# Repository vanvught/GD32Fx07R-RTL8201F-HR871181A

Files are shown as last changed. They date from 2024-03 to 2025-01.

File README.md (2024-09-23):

# GD32Fx07R development board with RTL8201F and HR871181A

This board can be used with the `GD32F107Rx` , `GD32F207Rx`, `GD32F407Rx` MCU's. 

More information [https://www.gd32-dmx.org/dev-board.html](https://www.gd32-dmx.org/dev-board.html)



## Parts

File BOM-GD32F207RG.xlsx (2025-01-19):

Qty | Designator | Footprint | Comment | LCSC Part #
19 | C1, C3, C8, C9, C10, C11, C12, C13, C16, C17, C18, C19, C20, C22, C23, C24, C25, C26, C27 | C0603 | 100n | C14663
2 | C2, C4 | C0603 | 20pF | C38523
1 | C28 | C1206 | 1nF/2kV | C9196
2 | C5, C6 | C0603 | 12pF | C38523
4 | C7, C14, C15, C21 | A/3216-18R | 10uF | C7171
2 | D1, D2 | SOD323-R | 1N5819 | C191023
2 | FL1, FL2 | 603 | MZAS1608G121-1R3TF0603 | C709642
1 | IC1 | QFN50P500X500X100-33N | RTL8201F-VB-CG | C45044
1 | J4 | 10118192-0002LF | 10118192-0002LF | C2972784
1 | J6 | HR871181A | HR871181A | C49312
4 | LED1, LED2, LED3, LED4 | CHIP-LED0603 | LED | C2286
1 | Q1 | CSM-7X-DU | 25 MHz | C14872
1 | Q2 | 3.2X1.5 | 32.768kHz | C32346
3 | R1, R2, R9 | R0603 | 10K | C25804
2 | R14, R15 | R0603 | 510 | C23193
1 | R21 | R0603 | 2K49 | C100897
1 | R3 | R0603 | 1M | C22935
2 | R4, R12 | R0603 | 1K5 | C22843
4 | R5, R7, R17, R18 | R0603 | 22R | C23345
8 | R6, R8, R10, R11, R13, R16, R19, R20 | R0603 | 4K7 | C23162
1 | RN1 | 4X0402ARV341 | 2K | C44891
2 | RN2, RN3 | 4X0402ARV341 | 33 | C25501
1 | SW1 | EVQ-Q2 | BOOT0 | C221880
1 | SW2 | EVQ-Q2 | KEY1 | C221880
1 | SW3 | EVQ-Q2 | KEY2 | C221880
1 | SW4 | EVQ-Q2 | RESET | C221880
1 | U1 | SO08-EIAJ | W25Q128JVSIQ | C97521
1 | U2 | LQFP64 | GD32F207RGT6 | C2976322
1 | U3 | SOT23-5 | AP2112-3.3 | C51118
72

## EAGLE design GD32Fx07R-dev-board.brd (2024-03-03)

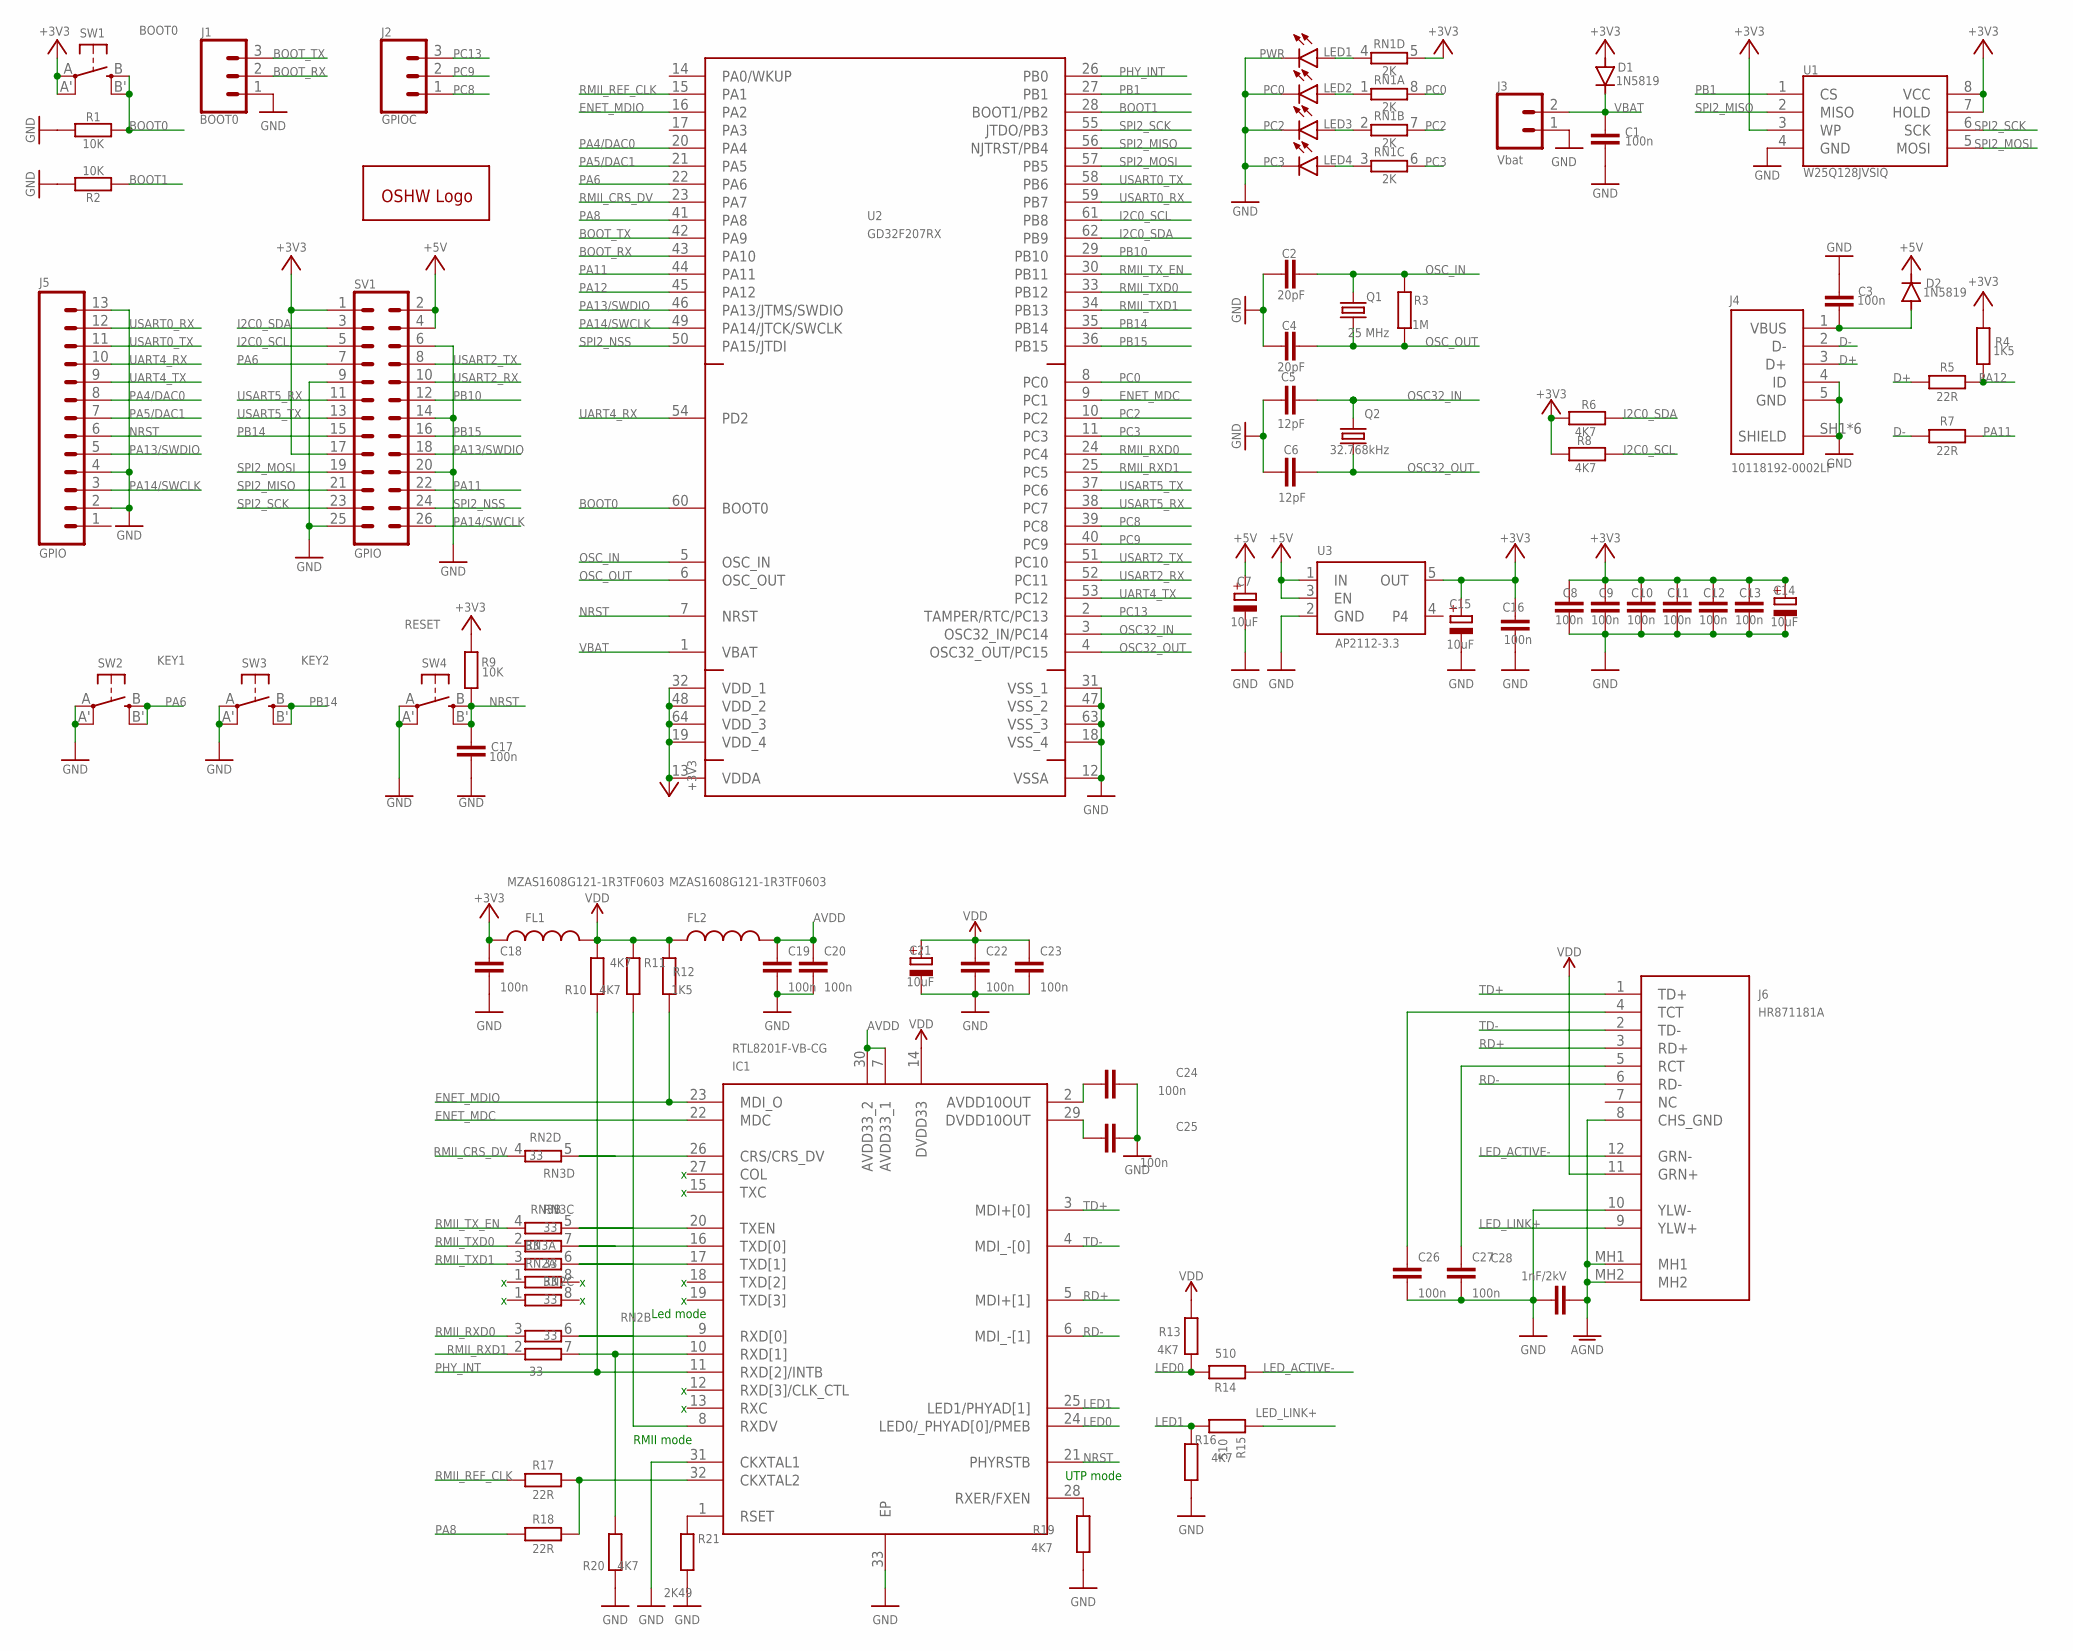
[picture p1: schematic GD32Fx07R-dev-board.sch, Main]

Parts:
C1, C3, C8, C9, C10, C11, C12, C13, C16, C17, C18, C19, C20, C22, C23, C24, C25, C26, C27: 100n; C0603; JLCPCB C14663
C2, C4: 20pF; C0603; JLCPCB C38523
C5, C6: 12pF; C0603; JLCPCB C38523
C7, C14, C15, C21: 10uF; A/3216-18R; JLCPCB C7171
C28: 1nF/2kV; C1206; JLCPCB C9196
D1, D2: 1N5819; SOD323-R; JLCPCB C191023
FL1, FL2: MZAS1608G121-1R3TF0603; 0603
GOLD_ORB_SM1: OSHWLOGOLOGO5MM; OSHW_5MM
IC1: RTL8201F-VB-CG; QFN50P500X500X100-33N
J1: BOOT0; 1X03
J2: GPIOC; 1X03
J3: Vbat; 1X02_NO_SILK
J4: 10118192-0002LF; JLCPCB C2972784
J5: GPIO; 1X13
J6: HR871181A
LED1: PWR; CHIP-LED0603; JLCPCB C72043
LED2: PC0; CHIP-LED0603; JLCPCB C72043
LED3: PC2; CHIP-LED0603; JLCPCB C72043
LED4: PC3; CHIP-LED0603; JLCPCB C72043
Q1: 25 MHz; CSM-7X-DU; JLCPCB C14872
Q2: 32.768kHz; 3.2X1.5; JLCPCB C32346
R1, R2, R9: 10K; R0603; JLCPCB C25804
R3: 1M; R0603; JLCPCB C22935
R4, R12: 1K5; R0603; JLCPCB C22843
R5, R7, R17, R18: 22R; R0603; JLCPCB C23345
R6, R8, R10, R11, R13, R16, R19, R20: 4K7; R0603; JLCPCB C23162
R14, R15: 510; R0603; JLCPCB C23193
R21: 2K49; R0603; JLCPCB C100897
RN1: 2K; 4X0402ARV341; JLCPCB C44891
RN2, RN3: 33; 4X0402ARV341; JLCPCB C25501
SV1: GPIO; MA13-2
SW1: BOOT0; EVQ-Q2; JLCPCB C221880
SW2: KEY1; EVQ-Q2; JLCPCB C221880
SW3: KEY2; EVQ-Q2; JLCPCB C221880
SW4: RESET; EVQ-Q2; JLCPCB C221880
U1: W25Q128JVSIQ; SO08-EIAJ; JLCPCB C97521
U2: GD32F207RX; LQFP64
U3: AP2112-3.3; SOT23-5; JLCPCB C51118

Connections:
+3V3: C8.1, C9.1, C10.1, C11.1, C12.1, C13.1, C14.+, C15.+, C16.1, C18.1, D1.A, FL1.1, R4.2, R6.2, R8.2, R9.2, RN1.5 (2), SV1.1, SV1.17, SW1.A, SW1.A' (P1), U1.3 (WP), U1.7 (HOLD), U1.8 (VCC), U2.13 (VDDA), U2.19 (VDD_4), U2.32 (VDD_1), U2.48 (VDD_2), U2.64 (VDD_3), U3.5 (OUT)
+5V: C7.+, D2.C, SV1.2, SV1.4, U3.1 (IN), U3.3 (EN)
AGND: C28.2, J6.8 (CHS_GND), J6.MH1, J6.MH2
AVDD: C19.1, C20.1, FL2.2, IC1.7 (AVDD33_1), IC1.30 (AVDD33_2)
BOOT0: R1.2, SW1.B (S), SW1.B' (S1), U2.60 (BOOT0)
BOOT1: R2.1, U2.28 (BOOT1/PB2)
BOOT_RX: J1.2, U2.43 (PA10)
BOOT_TX: J1.3, U2.42 (PA9)
CLOCK: IC1.32 (CKXTAL2), R17.2, R18.2
D+: J4.3 (D+), R5.1
D-: J4.2 (D-), R7.1
ENET_MDC: IC1.22 (MDC), U2.9 (PC1)
ENET_MDIO: IC1.23 (MDI_O), R12.1, U2.16 (PA2)
GND: C1.2, C2.1, C3.1, C4.1, C5.1, C6.1, C7.-, C8.2, C9.2, C10.2, C11.2, C12.2, C13.2, C14.-, C15.-, C16.2, C17.2, C18.2, C19.2, C20.2, C21.-, C22.2, C23.2, C24.1, C25.1, C26.2, C27.2, C28.1, IC1.31 (CKXTAL1), IC1.33 (EP), J1.1, J3.1, J4.4 (ID), J4.5 (GND), J4.SH1 (SHIELD), J4.SH2 (SHIELD), J4.SH3 (SHIELD), J4.SH4 (SHIELD), J4.SH5 (SHIELD), J4.SH6 (SHIELD), J5.2, J5.4, J5.13, J6.10 (YLW-), LED1.C, LED2.C, LED3.C, LED4.C, R1.1, R2.2, R16.1, R19.1, R20.1, R21.2, SV1.6, SV1.9, SV1.14, SV1.20, SV1.25, SW2.A, SW2.A' (P1), SW3.A, SW3.A' (P1), SW4.A, SW4.A' (P1), U1.4 (GND), U2.12 (VSSA), U2.18 (VSS_4), U2.31 (VSS_1), U2.47 (VSS_2), U2.63 (VSS_3), U3.2 (GND)
I2C0_SCL: R8.1, SV1.5, U2.61 (PB8)
I2C0_SDA: R6.1, SV1.3, U2.62 (PB9)
LED0: IC1.24 (LED0/_PHYAD[0]/PMEB), R13.1, R14.2
LED1: IC1.25 (LED1/PHYAD[1]), R15.2, R16.2
LED_ACTIVE-: J6.12 (GRN-), R14.1
LED_LINK+: J6.9 (YLW+), R15.1
unnamed: C24.2, IC1.2 (AVDD10OUT)
unnamed: IC1.1 (RSET), R21.1
unnamed: IC1.8 (RXDV), R11.2
unnamed: C25.2, IC1.29 (DVDD10OUT)
unnamed: IC1.28 (RXER/FXEN), R19.2
unnamed: C27.1, J6.5 (RCT)
unnamed: LED2.A, RN1.1
unnamed: LED3.A, RN1.2 (1)
unnamed: C26.1, J6.4 (TCT)
unnamed: LED4.A, RN1.3 (1)
unnamed: LED1.A, RN1.4 (1)
NRST: C17.1, IC1.21 (PHYRSTB), J5.6, R9.1, SW4.B (S), SW4.B' (S1), U2.7 (NRST)
OSC32_IN: C5.2, Q2.2, U2.3 (OSC32_IN/PC14)
OSC32_OUT: C6.2, Q2.1, U2.4 (OSC32_OUT/PC15)
OSC_IN: C2.2, Q1.2, R3.1, U2.5 (OSC_IN)
OSC_OUT: C4.2, Q1.1, R3.2, U2.6 (OSC_OUT)
PA4/DAC0: J5.8, U2.20 (PA4)
PA5/DAC1: J5.7, U2.21 (PA5)
PA6: SV1.7, SW2.B (S), SW2.B' (S1), U2.22 (PA6)
PA8: R18.1, U2.41 (PA8)
PA11: R7.2, SV1.22, U2.44 (PA11)
PA12: R4.1, R5.2, U2.45 (PA12)
PA13/SWDIO: J5.5, SV1.18, U2.46 (PA13/JTMS/SWDIO)
PA14/SWCLK: J5.3, SV1.26, U2.49 (PA14/JTCK/SWCLK)
PB1: U1.1 (CS), U2.27 (PB1)
PB10: SV1.12, U2.29 (PB10)
PB14: SV1.15, SW3.B (S), SW3.B' (S1), U2.35 (PB14)
PB15: SV1.16, U2.36 (PB15)
PC0: RN1.8 (2), U2.8 (PC0)
PC2: RN1.7 (2), U2.10 (PC2)
PC3: RN1.6 (2), U2.11 (PC3)
PC8: J2.1, U2.39 (PC8)
PC9: J2.2, U2.40 (PC9)
PC13: J2.3, U2.2 (TAMPER/RTC/PC13)
PHY_INT: IC1.11 (RXD[2]/INTB), R10.1, U2.26 (PB0)
RD+: IC1.5 (MDI+[1]), J6.3 (RD+)
RD-: IC1.6 (MDI_-[1]), J6.6 (RD-)
RMII_CRS_DV: RN2.4 (1), U2.23 (PA7)
RMII_REF_CLK: R17.1, U2.15 (PA1)
RMII_RXD0: RN2.3 (1), U2.24 (PC4)
RMII_RXD1: RN2.2 (1), U2.25 (PC5)
RMII_TXD0: RN3.2 (1), U2.33 (PB12)
RMII_TXD1: RN3.3 (1), U2.34 (PB13)
RMII_TX_EN: RN3.4 (1), U2.30 (PB11)
RXD0: IC1.9 (RXD[0]), RN2.6 (2)
RXD1: IC1.10 (RXD[1]), R20.2, RN2.7 (2)
RXDV: IC1.26 (CRS/CRS_DV), RN2.5 (2)
SPI2_MISO: SV1.21, U1.2 (MISO), U2.56 (NJTRST/PB4)
SPI2_MOSI: SV1.19, U1.5 (MOSI), U2.57 (PB5)
SPI2_NSS: SV1.24, U2.50 (PA15/JTDI)
SPI2_SCK: SV1.23, U1.6 (SCK), U2.55 (JTDO/PB3)
TD+: IC1.3 (MDI+[0]), J6.1 (TD+)
TD-: IC1.4 (MDI_-[0]), J6.2 (TD-)
TXD0: IC1.16 (TXD[0]), RN3.7 (2)
TXD1: IC1.17 (TXD[1]), RN3.6 (2)
TXEN: IC1.20 (TXEN), RN3.5 (2)
UART4_RX: J5.10, U2.54 (PD2)
UART4_TX: J5.9, U2.53 (PC12)
USART0_RX: J5.12, U2.59 (PB7)
USART0_TX: J5.11, U2.58 (PB6)
USART2_RX: SV1.10, U2.52 (PC11)
USART2_TX: SV1.8, U2.51 (PC10)
USART5_RX: SV1.11, U2.38 (PC7)
USART5_TX: SV1.13, U2.37 (PC6)
VBAT: C1.1, D1.C, J3.2, U2.1 (VBAT)
VBUS: C3.2, D2.A, J4.1 (VBUS)
VDD: C21.+, C22.1, C23.1, FL1.2, FL2.1, IC1.14 (DVDD33), J6.11 (GRN+), R10.2, R11.1, R12.2, R13.2

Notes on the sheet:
RMII mode
UTP mode
Led mode

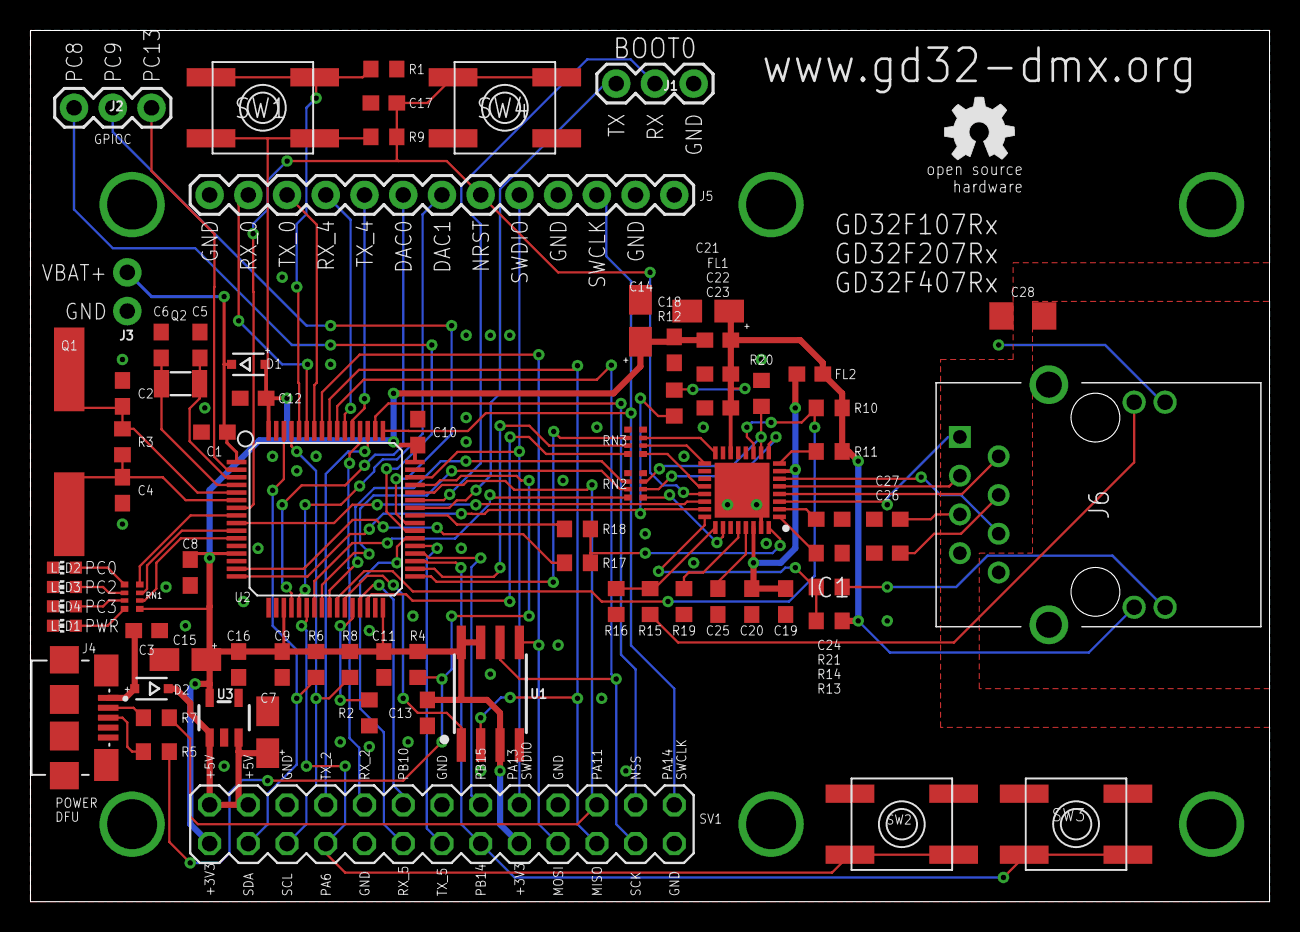
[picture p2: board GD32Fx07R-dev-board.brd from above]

Board: 2 copper layers, 81.3 x 57.1 mm, 78 parts (0 on the bottom side), 87 nets.

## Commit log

2024-03-03 Initial commit
    @particlerain
    [BOM-GD32F107RC.xlsx, BOM-GD32F207RG.xlsx, BOM-GD32F407RE.xlsx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]
2025-01-19 Updated BOM
    - Changed led part number
    [BOM-GD32F207RG.xlsx]

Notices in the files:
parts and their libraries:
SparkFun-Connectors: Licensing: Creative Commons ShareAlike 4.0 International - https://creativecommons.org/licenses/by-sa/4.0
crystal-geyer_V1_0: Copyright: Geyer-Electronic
